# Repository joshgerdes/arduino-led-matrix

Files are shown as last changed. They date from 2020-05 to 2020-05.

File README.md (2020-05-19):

# Arduino LED Matrix
 
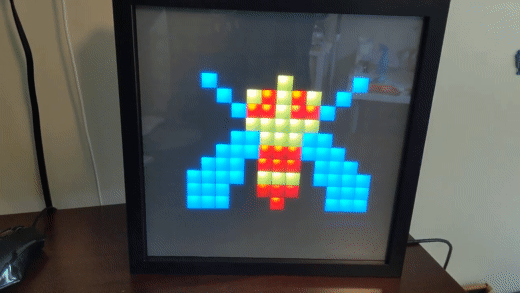
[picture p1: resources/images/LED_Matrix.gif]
Video of LED Matrix (https://www.youtube.com/watch?v=froi3urcf1Y)


 An Arduino powered 16x16 LED Matrix using the [FastLED](http://fastled.io/) library to drive a WS2812B LED array.

 ## Details

<div style="display: flex;">





</div>

## Wiring Diagram

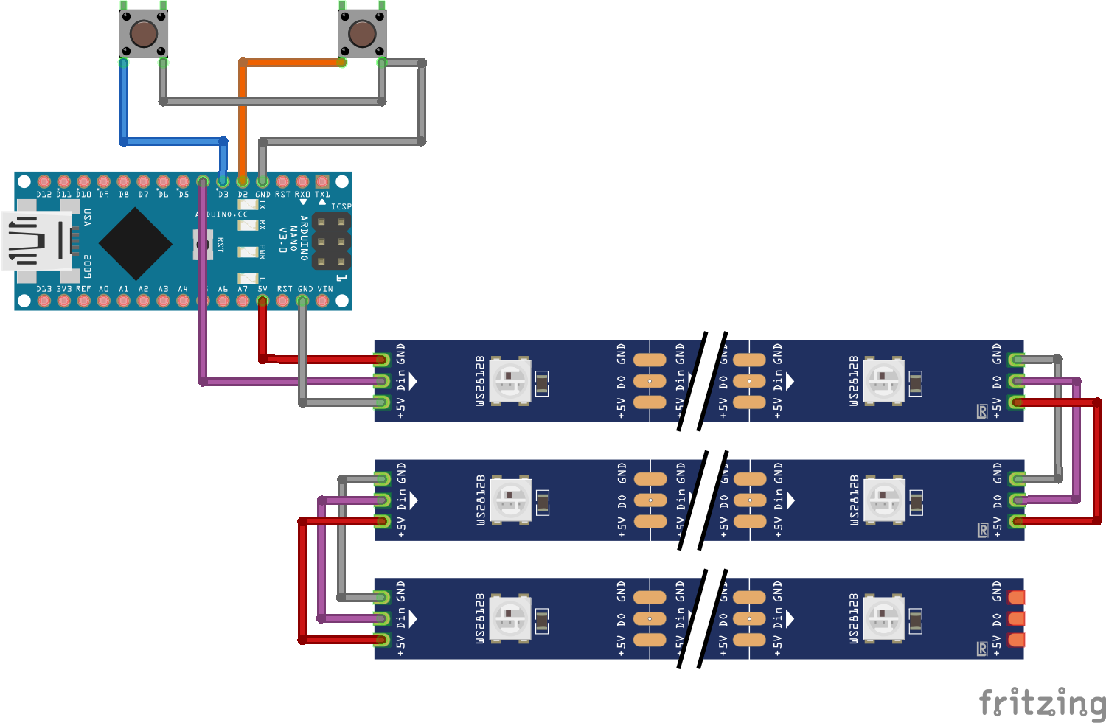
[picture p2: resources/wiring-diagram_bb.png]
Fritzing diagram sketch


## 3D Models

All models were created in [Tinkercad](https://www.tinkercad.com/) and exported in STL format.

- [Matrix Grid 1/4th - Side A](resources/models/LED_Matrix_4th_SideA.stl)
- [Matrix Grid 1/4th - Side B](resources/models/LED_Matrix_4th_SideB.stl)
- [Arduino Holder Base](resources/models/Nano_Holder_Base.stl)
- [Arduino Holder Lid](resources/models/Nano_Holder_Lid.stl)
  
## Materials List

| Part | Qty | |
|---|---|---|
| Arduino Nano | 1 | https://amzn.to/369SMRI |
| WS2812B Strip Light - 60 LEDs, 5M | 1  | https://ebay.to/2X7ta3L |
| 3 PIN Solderless LED Cable Connector For WS2812B WS2811 LED Strip Lamp 15cm  | 16  | https://ebay.to/2zTukYA |
| 12mm SPST NO Reset Switch Push Button | 2  | https://amzn.to/2WHkzFU |
| Breadboard Jumper Wires | 7 | https://amzn.to/36hR3d9 |
| Black Wood Shadow Box - 12" x 12" | 1 | https://www.hobbylobby.com/Home-Decor-Frames/Frames-Photo-Albums/Shadow-Boxes-Display-Cases/Black-Wood-Shadow-Box---12%22-x-12%22/p/39376 |
| Creatology poser board plastic 22" x 28" | 1 | https://www.michaels.com/pacon-plastic-poster-board-clear/10378153.html |
| Elmers Foamboard 950109 20" x 30" x 3/16" | 1 | https://www.michaels.com/elmers-foam-board-white/10110205.html |
| Command Strip Mini Hooks (17006CLR-ES) | 2 | https://amzn.to/3g5Rkoe |
| Electrical Tape | 1 | https://amzn.to/2Ti1JmR |

## Software & Other Resources

- Visual Studio Code - https://code.visualstudio.com/
- Arduino IDE - https://www.arduino.cc/en/Main/Software
- Ultimaker Cura - https://ultimaker.com/software/ultimaker-cura
- LCD Image Convertor - https://www.riuson.com/lcd-image-converter
- GIMP - https://www.gimp.org/
- Sprite Image Resources - https://www.spriters-resource.com/

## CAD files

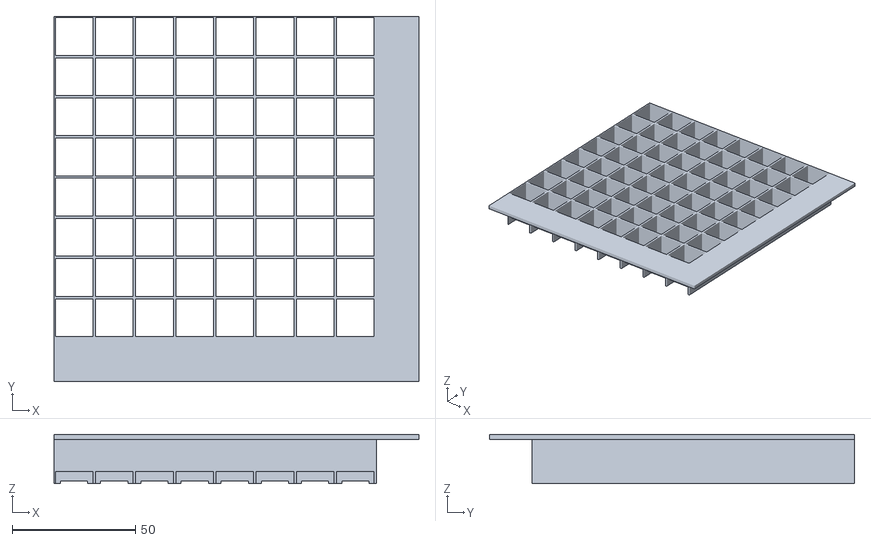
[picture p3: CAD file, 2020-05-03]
resources/models/LED_Matrix_4th_SideA.stl
147.9 x 148.0 x 20.0

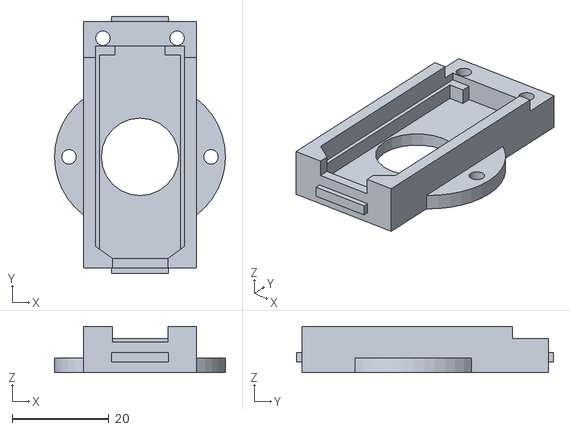
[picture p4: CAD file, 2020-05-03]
resources/models/Nano_Holder_Base.stl
35.3 x 53.1 x 9.50

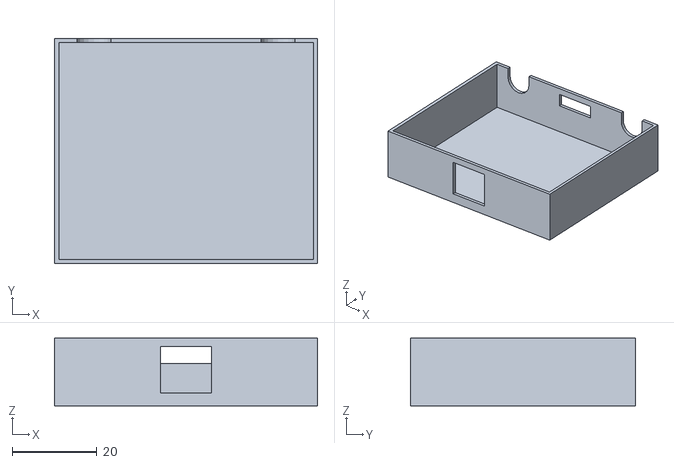
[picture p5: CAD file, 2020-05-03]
resources/models/Nano_Holder_Lid.stl
62.0 x 53.1 x 16.0

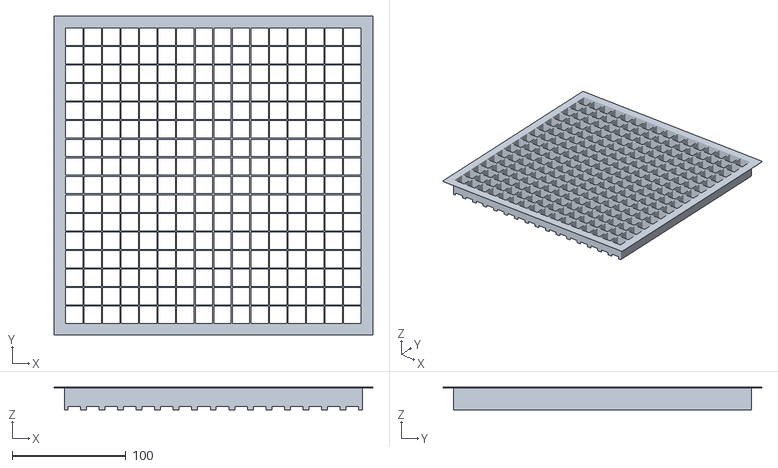
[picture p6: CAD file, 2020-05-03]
resources/models/LED_Matrix_16x16.stl
280.0 x 280.0 x 20.0

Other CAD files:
resources/models/LED_Matrix_4th_SideB.stl

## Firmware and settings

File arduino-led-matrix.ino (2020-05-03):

#include <avr/pgmspace.h>
#include "src/libraries/FastLED/FastLED.h"
#include "src/bitmaps/digdug.h"
#include "src/bitmaps/frogger.h"
#include "src/bitmaps/galaga.h"
#include "src/bitmaps/pacman.h"
#include "src/bitmaps/smb.h"
#include "src/bitmaps/qbert.h"

#define DATA_PIN        4
#define BUTTON_PIN      3
#define BUTTONTWO_PIN   2
#define NUM_LEDS        256
#define BRIGHTNESS      16
#define LED_TYPE        WS2812B
#define COLOR_ORDER     GRB
#define COLS            16

const int MAX_SELECTION = 4;
const int MAX_SELECTION_TWO[] = { 0, 3, 3, 4 };
 
CRGB leds[NUM_LEDS];

volatile int selection = 0;
volatile int selectionTwo = 0;
long lastDebounceTime = 0; 
long lastDebounceTimeTwo = 0;  
long debounce = 100;         

void setup() {
  delay(3000); // power-up safety delay
  Serial.begin(9600);
  
  FastLED.addLeds<LED_TYPE, DATA_PIN, COLOR_ORDER>(leds, NUM_LEDS);
  FastLED.setBrightness(BRIGHTNESS);
  FastLED.clear();

  pinMode(BUTTON_PIN, INPUT_PULLUP);
  attachInterrupt(digitalPinToInterrupt(BUTTON_PIN), buttonToggled, RISING);
  pinMode(BUTTONTWO_PIN, INPUT_PULLUP);
  attachInterrupt(digitalPinToInterrupt(BUTTONTWO_PIN), buttonTwoToggled, RISING);

  selection = 1;
  selectionTwo = 0;
  
  Serial.print("Setup Complete");
}

void drawBitmap(const long* bitmap) {
  FastLED.clear();
  bool LTR = true;
  for (int i = 0; i < NUM_LEDS; i++) {
    if (LTR) {
      for (int j = 0; j < COLS; j++) {
        leds[i + j] = pgm_read_dword(&(bitmap[i + j]));
      }
    } else {
      for (int j = COLS - 1; j > 0; j--) {
        leds[i + COLS - j] = pgm_read_dword(&(bitmap[i + j - 1]));
      }
    }

    i = i + COLS - 1;
    LTR = !LTR;
  }

  FastLED.show();
}

void drawAnimation(const long* bitmaps, int s, int delayTime) {
  for (int i = 0; i < s; i++) {
    drawBitmap(bitmaps[i]);
    delay(delayTime);
  }
}

void buttonToggled() {
  if (millis() - lastDebounceTime > debounce) {
    selectionTwo = 0;
    selection++;
    if (selection > MAX_SELECTION)  selection = 1;
    lastDebounceTime = millis();
  }
}

void buttonTwoToggled() {
  if (millis() - lastDebounceTimeTwo > debounce) {
    selectionTwo++;
    if (selectionTwo > MAX_SELECTION_TWO[selection])  selectionTwo = 0;
    lastDebounceTimeTwo = millis();
  }
}

void galagaLoop() {
  switch (selectionTwo) {
    case 1:
      drawAnimation(GalagaBoss, GalagaBossSize, 500);
      break;
    case 2:
      drawAnimation(GalagaGoei, GalagaGoeiSize, 500);
      break;
    case 3:
      drawAnimation(GalagaZako, GalagaZakoSize, 500);
      break;
    default:
      drawBitmap(GalagaShip);
      break;
  }
}

void digDugLoop() {
  switch (selectionTwo) {
    case 1:
      drawAnimation(DigDugTaizoShovel, DigDugTaizoShovelSize, 500);
      break;
    case 2:
      drawAnimation(DigDugPooka, DigDugPookaSize, 500);
      break;
    case 3:
      drawAnimation(DigDugFygar, DigDugFygarSize, 500);
      break;
    default:
      drawBitmap(DigDugTaizoShovel01);
      break;
  }
}

void miscLoop() {
  switch (selectionTwo) {
    case 1:
      drawAnimation(Frogger, FroggerSize, 500);
      break;
    case 2:
      drawAnimation(Qbert, QbertSize, 500);
      break;
    case 3:
      drawAnimation(PacManMsPac, PacManMsPacSize, 100);
      break;
    case 4:
      drawAnimation(PacManBlinky, PacManBlinkySize, 500);
      break;
    default:
      drawBitmap(SMBMario01);
      break;
  }
}

void loop() {
  switch (selection) {
    case 1:
      galagaLoop();
      break;
    case 2:
      digDugLoop();
      break;
    case 3:
      miscLoop();
      break;
  }
}
